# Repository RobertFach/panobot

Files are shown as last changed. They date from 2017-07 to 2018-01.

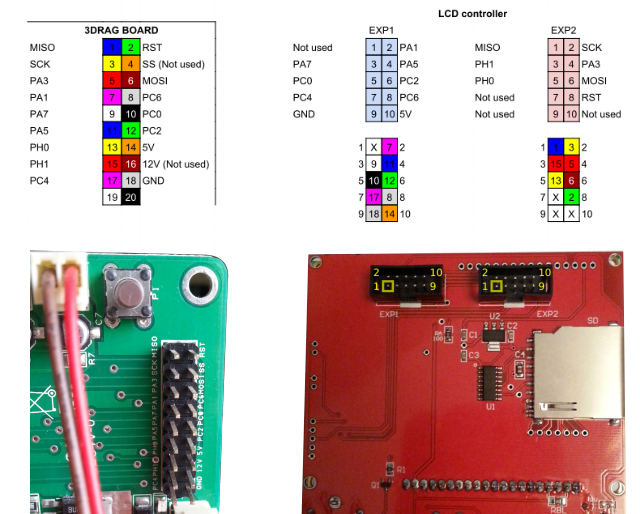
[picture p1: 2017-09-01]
hardware/pin_table-full-graphic-smart-controller.png

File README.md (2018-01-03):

PANOBOT: A Panorama robot, version 1

Panobot is a full automatic robot, which can be used to create Panoramas and Gigapixels with small and large cameras (like DSLRs). The camera is mounted on a turret to allow pan/tilt motion. After programming the capture parameters, the robot will start to rotate the camera, taking one (or multiple) pictures per position and making sure that the capture positions have enough overlap.

Panobot has the following menu features:
 * Scan
   * starts a scan
 * Sphere
   * starts a spherical scan (360x180)
 * Take picture
   * allows to manually take a picture, this is usefull for testing the camera trigger connection
 * Setup
   * Pan Left, Pan Right, Tilt Up, Tilt Down
     * defines the scan area of the panorama/gigapixel, the head will move while the range is defined, this is used for a normal scan
   * Image P-Delay
     * the longer, the more time the camera has to measure and (eventually focus, if not in manual camera mode), triggers focusing of camera
   * Image Delay
     * the delay it take for the camera to write the image to the card and/or the time it needs to stabilize the mechanical system due to rotating motion
   * Shutter Delay
     * how long the shutter will be pressed
   * Focal Length
     * the focal length which is currently by the camera
   * Horizontal& Vertical Overlap
     * defines the overlap between consecutive images, a value between 30% and 50% makes sense, usually depends on the capture situation
   * Crop factor
     * in combination with the focal length, can be used to calculate field of view, which is required for horizontal&vertical overlap

Required Hardware:
 * 3d printed parts
   * Please have a look at [Panobot at Thingiverse](https://www.thingiverse.com/thing:2503118) to find out the parts that need to be printed
 * mechanical parts
   * some screws, washers, nuts M3, M4
   * some bearings 608 (around 10)
   * some rods 8mm (for structure and as axis)
 * electronic parts
   * 2 stepper motors Nema17, like 42BYGHM810
   * Arduino Mega 2560
   * Reprap Full Graphic SmartLCD with clickencoder
   * the controller PCB in version 1.1.0, which consists of two stepper drivers A4988 and two optocopplers; you can build your own pcb (see pcb folder) or get one...

Required Software:
   * install atom editor
     * https://atom.io/ -> install deb
   * follow steps on http://platformio.org/get-started/ide?install=atom
     * install platformio-ide package inside atom
   * code completion
     * apt-get install clang

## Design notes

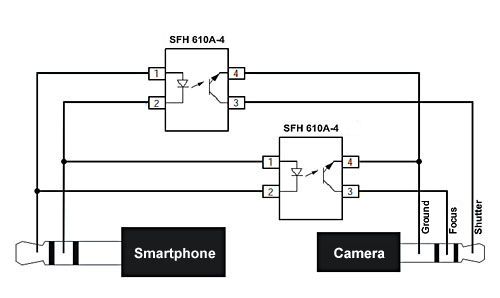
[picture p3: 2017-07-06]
hardware/OPTO-Canon-Trigger.jpeg

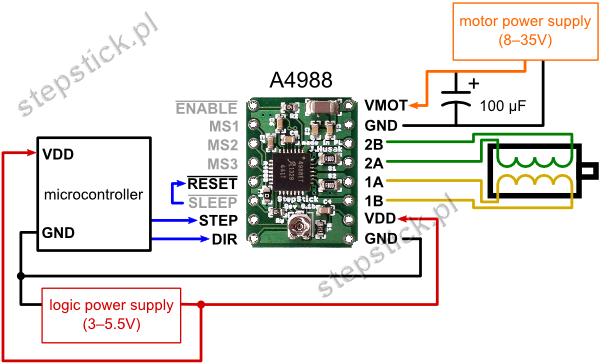
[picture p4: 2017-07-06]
hardware/stepstick-a4988.png

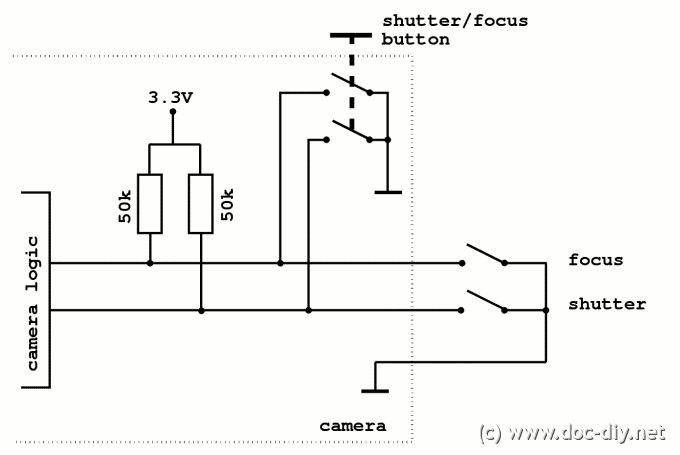
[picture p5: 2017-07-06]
hardware/canon-eos-remote-shutter.png

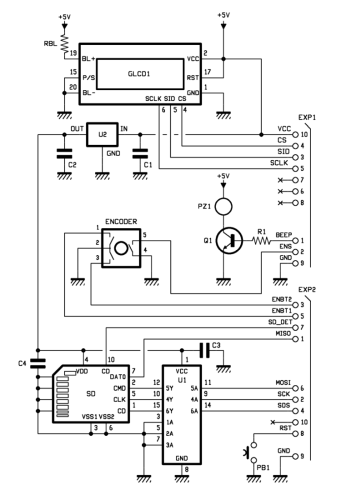
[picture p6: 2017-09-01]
hardware/1193_Schema-full-graphic-smart-controller.png

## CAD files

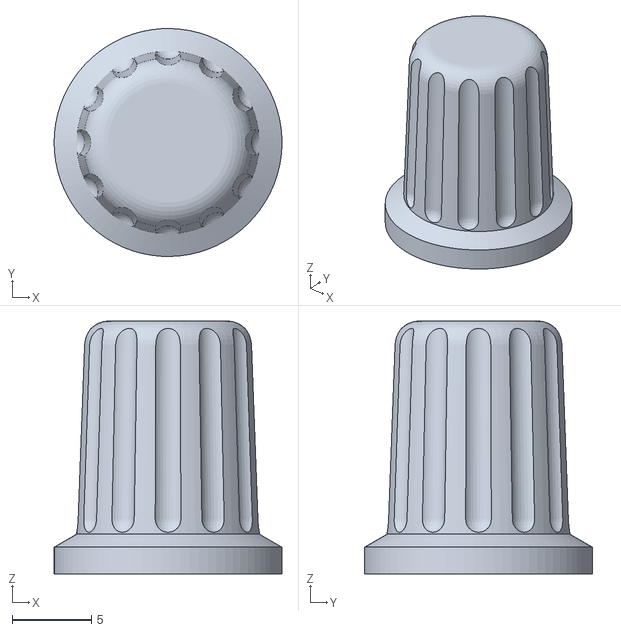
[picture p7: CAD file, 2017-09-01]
model/Case_for_the_Full_Graphic_Smart_LCD_Controller/files/controller_knob_2.stl
14.4 x 14.4 x 16.0

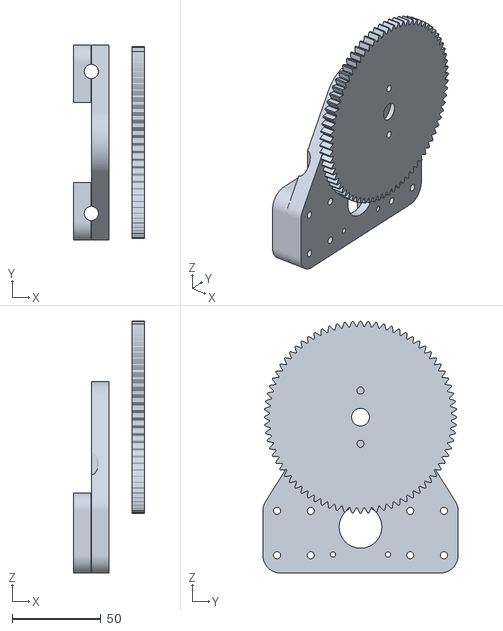
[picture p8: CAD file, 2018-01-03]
model/improved_tilt_axis.stl
40.1 x 110.0 x 141.9

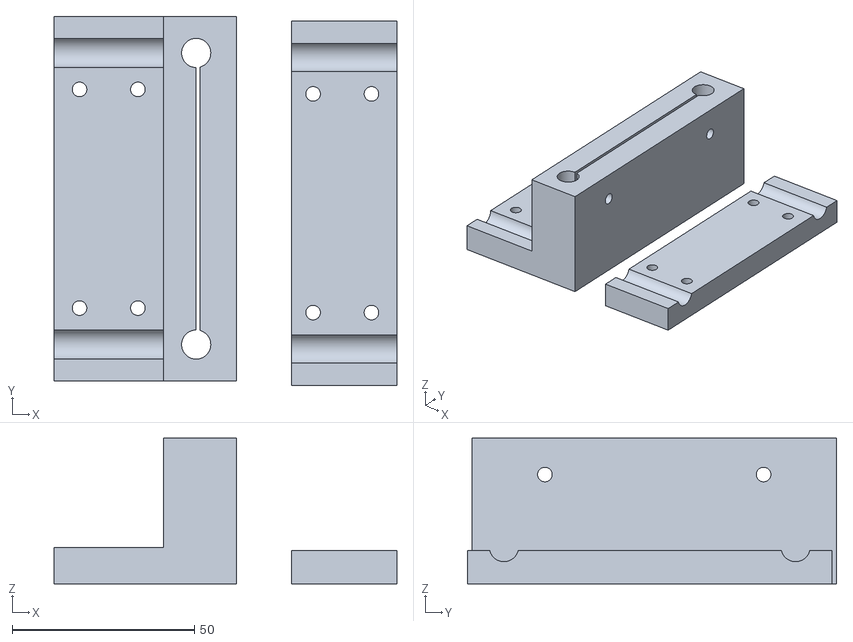
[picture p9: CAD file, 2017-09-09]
model/print/pantiltconnector_print.stl
94.1 x 101.2 x 40.0

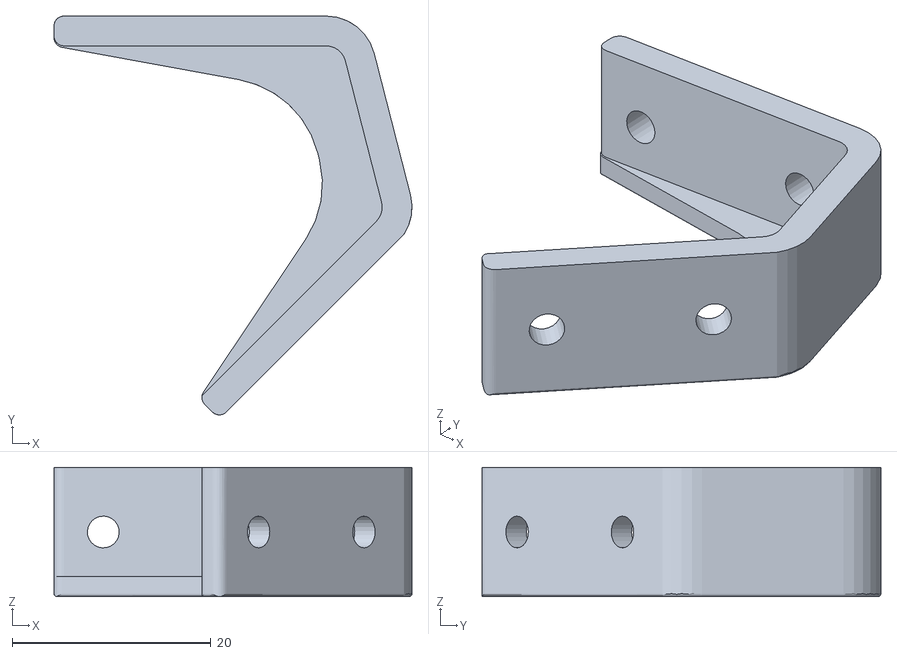
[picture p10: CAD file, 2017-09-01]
model/Case_for_the_Full_Graphic_Smart_LCD_Controller/files/mount_18_mm.stl
36.0 x 40.1 x 13.0

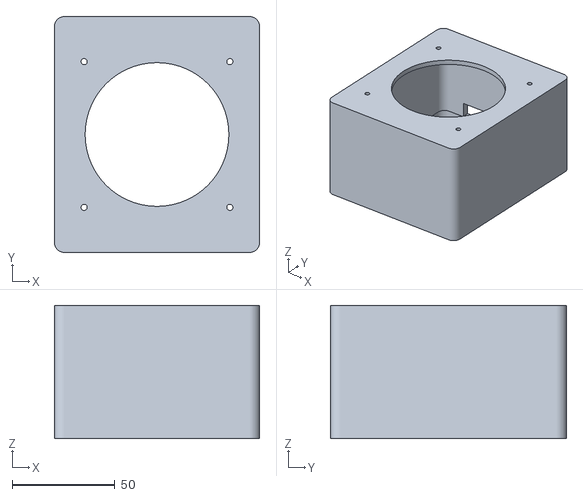
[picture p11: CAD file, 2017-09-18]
model/controller_case_cover.stl
100.0 x 115.0 x 65.0

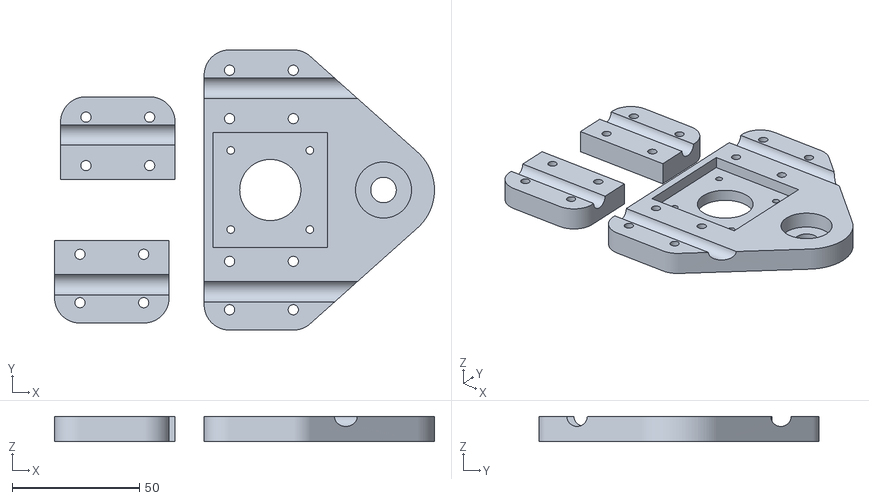
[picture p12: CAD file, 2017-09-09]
model/print/tiltsteppermount_print.stl
149.1 x 110.0 x 10.0

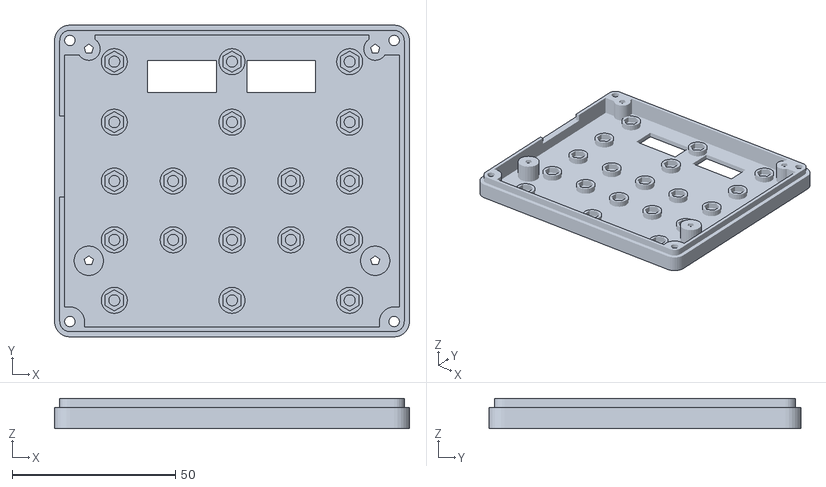
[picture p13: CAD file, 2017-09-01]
model/Case_for_the_Full_Graphic_Smart_LCD_Controller/files/Bottom_Case_FGD-_pockets.stl
108.6 x 95.4 x 9.30

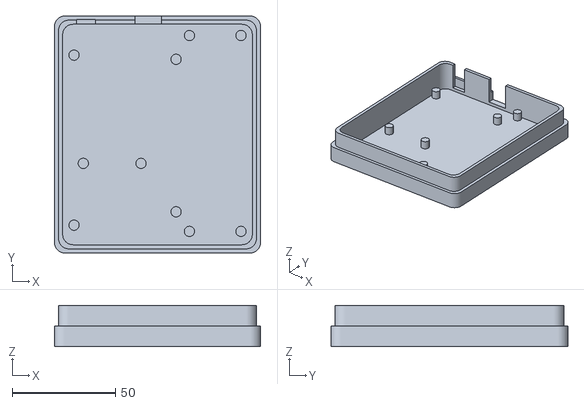
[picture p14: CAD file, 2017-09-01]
model/controller_case_bottom.stl
100.0 x 115.0 x 20.0

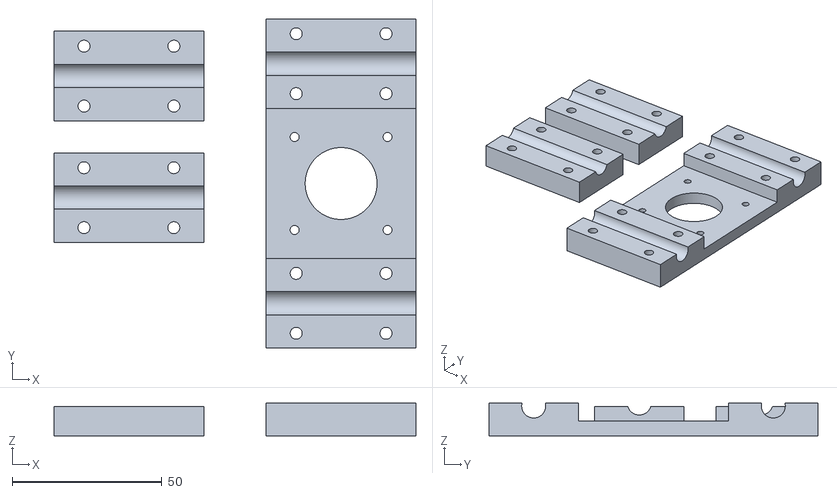
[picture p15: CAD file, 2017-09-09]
model/print/stepper_pan_mount_print.stl
120.9 x 110.0 x 11.0

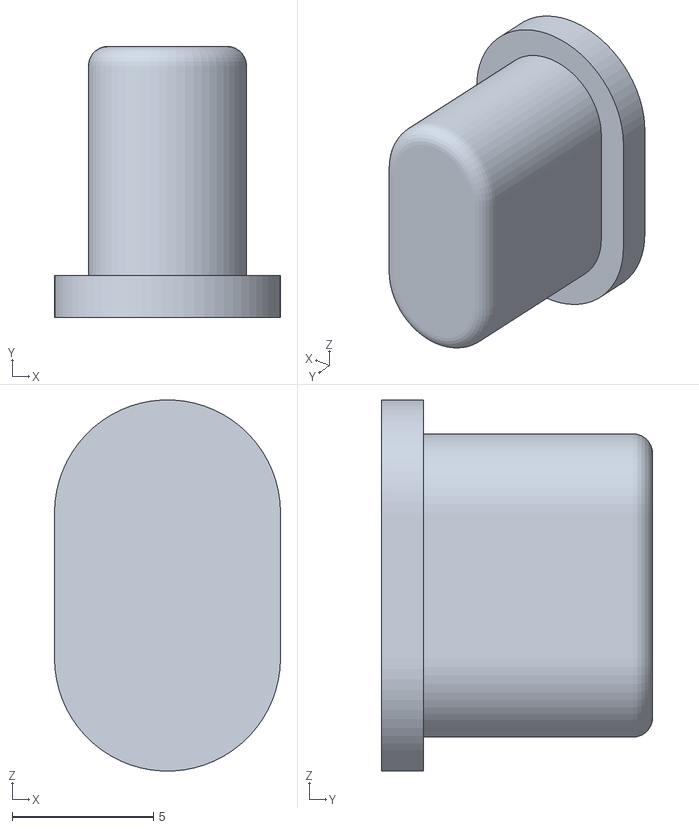
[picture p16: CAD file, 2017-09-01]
model/Case_for_the_Full_Graphic_Smart_LCD_Controller/files/Kill_Button_FGD.stl
8.00 x 9.60 x 13.1

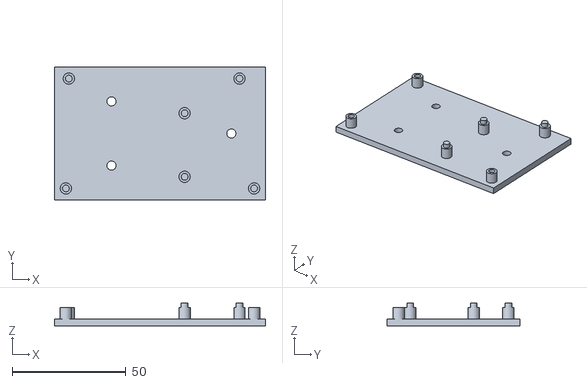
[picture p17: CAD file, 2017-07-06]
model/megamount.stl
92.6 x 58.2 x 10.00

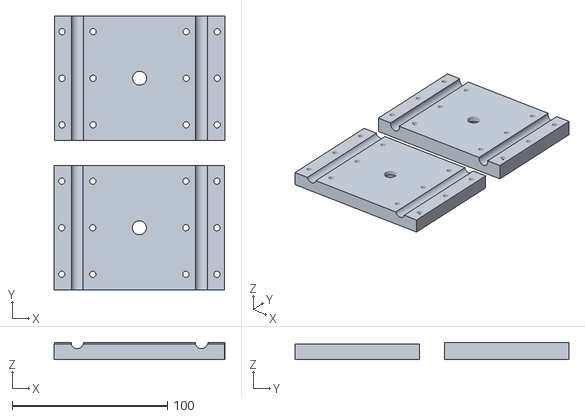
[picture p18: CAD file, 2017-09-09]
model/print/central_pan_print.stl
110.2 x 176.3 x 11.0

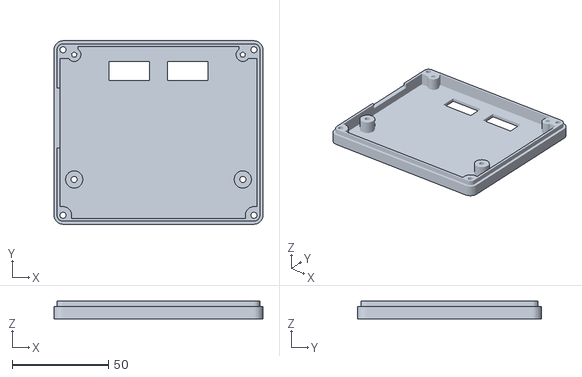
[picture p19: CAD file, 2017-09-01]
model/Case_for_the_Full_Graphic_Smart_LCD_Controller/files/Bottom_Case_FGD.stl
108.6 x 95.4 x 9.30

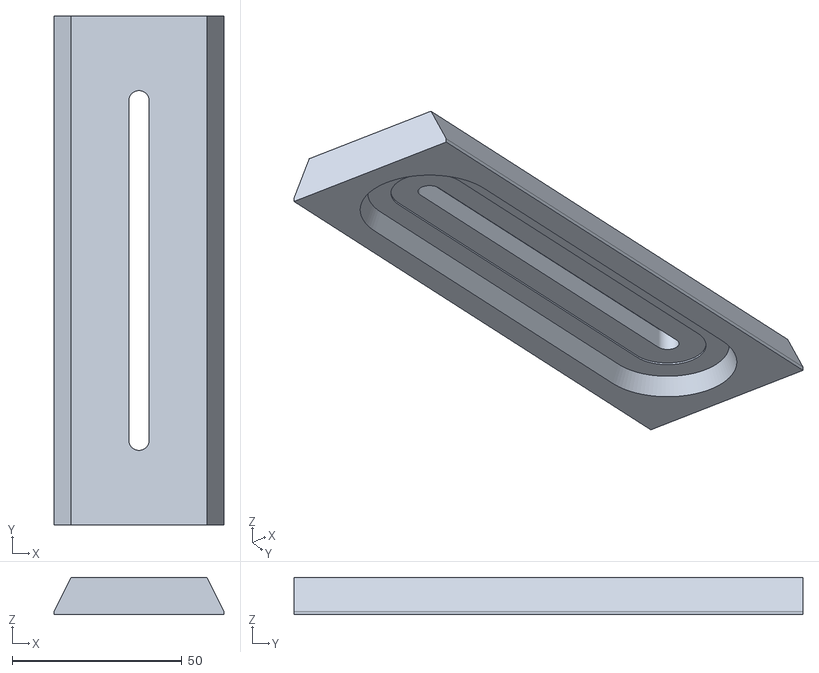
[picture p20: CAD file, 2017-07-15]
model/print/camquickmount_andoer.stl
50.0 x 150.0 x 11.0

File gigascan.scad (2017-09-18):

use <MCAD/involute_gears.scad>
use <MCAD/bearing.scad>
use <MCAD/nuts_and_bolts.scad>
use <MCAD/motors.scad>
include <MCAD/stepper.scad>
include <MCAD/boxes.scad>

$fn=100;

module mountgear() {
difference() {
union() {
    gear (
	number_of_teeth=81,
	circular_pitch=250, diametral_pitch=20,
	pressure_angle=28,
	clearance = 0.2,
	gear_thickness=7,
	rim_thickness=15,
	rim_width=5,
	hub_thickness=10,
	hub_diameter=15,
	bore_diameter=5,
	circles=0,
	backlash=0,
	twist=0,
	involute_facets=0,
	flat=false);
    //cylinder(r=15,h=20);
    cylinder(r1=45,r2=15,h=20);
}   
    translate([0,0,20-7+0.01])bearing(608,outline=true);
    translate([0,0,-0.01])bearing(608,outline=true);
    cylinder(r=4.1,h=50,center=true);
    
    rotate([0,0,45])translate([25,0,10+0.01])rotate([180,0,0])nutHole(4);
    rotate([0,0,45])translate([25,0,-0.01])cylinder(r=2,h=20);
    rotate([0,0,45])translate([25,0,10])cylinder(r=5,h=20);

    rotate([0,0,45])translate([-25,0,10+0.01])rotate([180,0,0])nutHole(4);
    rotate([0,0,45])translate([-25,0,-0.01])cylinder(r=2,h=20);
    rotate([0,0,45])translate([-25,0,10])cylinder(r=5,h=20);
}

}

module drivegear() {
    union() {
translate([56.25+9.02,0,0])gear (
	number_of_teeth=13,
	circular_pitch=250, diametral_pitch=20,
	pressure_angle=28,
	clearance = 0.2,
	gear_thickness=10,
	rim_thickness=15,
	rim_width=5,
	hub_thickness=10,
	hub_diameter=15,
	bore_diameter=5,
	circles=0,
	backlash=0,
	twist=0,
	involute_facets=0,
	flat=false);
        translate([56.25+9.02+1.9,-4,0])cube([3,8,15]);
    }
}

module pan() {
    difference() {
        union() {
            translate([-55,-40,21])cube([110,80,21]);
            translate([0,0,22])cylinder(r=15,h=20);
        }
        rotate([90,0,0])translate([40,31,-150])cylinder(r=4,h=300);
        rotate([90,0,0])translate([-40,31,-150])cylinder(r=4,h=300);
    //translate([0,56.25+9.02,28])rotate([180,0,0])stepper_motor_mount(17);
    
    cylinder(r=4.5,h=100);
    translate([0,0,20.9])bearing(608,outline=true);    
    translate([0,0,35.1])bearing(608,outline=true);
//    translate([20,23,31])minkowski(){
//        cylinder(r=8,h=10);
//        sphere(r=5);
//    }
//    translate([-20,23,31])minkowski(){
//        cylinder(r=8,h=10);
//        sphere(r=5);
//    }
//    translate([20,-23,31])minkowski(){
//        cylinder(r=8,h=10);
//        sphere(r=5);
//    }
//    translate([-20,-23,31])minkowski(){
//        cylinder(r=8,h=10);
//        sphere(r=5);
//    }
    translate([-150,-150,32])cube([300,300,0.1]);
    translate([30,30,0])cylinder(r=2,h=50);
    translate([50,30,0])cylinder(r=2,h=50);
    translate([30,0,0])cylinder(r=2,h=50);
    translate([50,0,0])cylinder(r=2,h=50);
    translate([30,-30,0])cylinder(r=2,h=50);
    translate([50,-30,0])cylinder(r=2,h=50);

    translate([-30,30,0])cylinder(r=2,h=50);
    translate([-50,30,0])cylinder(r=2,h=50);
    translate([-30,0,0])cylinder(r=2,h=50);
    translate([-50,0,0])cylinder(r=2,h=50);
    translate([-30,-30,0])cylinder(r=2,h=50);
    translate([-50,-30,0])cylinder(r=2,h=50);

  }    
}

module stepper() {
    motor(model=Nema17, size=NemaLong, dualAxis=false, pos=[56.25+9.02,0,25], orientation = [0,0,0]);
}

module steppermount() {
    difference() {
        translate([56.25+9.02-25,-55,21])cube([50,110,21]);
        //stepper();
        rotate([90,0,90])translate([40,31,-150])cylinder(r=4,h=300);
        rotate([90,0,90])translate([-40,31,-150])cylinder(r=4,h=300);        
    translate([56.25+9.02-26,-25,26])cube([55,50,30]);
    translate([56.25+9.02-25,-55,32])cube([300,300,0.1]);

    translate([56.25+9.02+31.04/2,31.04/2,0])cylinder(r=1.5,h=50);    
    translate([56.25+9.02-31.04/2,31.04/2,0])cylinder(r=1.5,h=50);    
    translate([56.25+9.02+31.04/2,-31.04/2,0])cylinder(r=1.5,h=50);    
    translate([56.25+9.02-31.04/2,-31.04/2,0])cylinder(r=1.5,h=50);
    
    translate([56.25+9.02,0,0])cylinder(r=12,h=50);    
        
    translate([56.25+9.02-15,30,0])cylinder(r=2,h=50);
    translate([56.25+9.02-15,50,0])cylinder(r=2,h=50);
    translate([56.25+9.02+15,30,0])cylinder(r=2,h=50);
    translate([56.25+9.02+15,50,0])cylinder(r=2,h=50);
        
    translate([56.25+9.02-15,-30,0])cylinder(r=2,h=50);
    translate([56.25+9.02-15,-50,0])cylinder(r=2,h=50);
    translate([56.25+9.02+15,-30,0])cylinder(r=2,h=50);
    translate([56.25+9.02+15,-50,0])cylinder(r=2,h=50);
    }
}

module panrods() {
    rotate([90,0,90])translate([40,31,-150])cylinder(r=4,h=300);
    rotate([90,0,90])translate([-40,31,-150])cylinder(r=4,h=300);    
}

module tiltsiderods() {
    rotate([0,0,90])translate([40,130,35])cylinder(r=4,h=100);
    rotate([0,0,90])translate([-40,130,35])cylinder(r=4,h=100);    
}

module tiltbaserods() {
    rotate([90,0,90])translate([30,100,-100.1])cylinder(r=4,h=200.2);
    rotate([90,0,90])translate([-30,100,-100.1])cylinder(r=4,h=200.2);    
}

module tiltside() {
    difference() {
        hull() {
            rotate([90,0,90])translate([0,145,100-10])cylinder(r=20,h=10);
            rotate([90,0,90])translate([-30,100,100-10])cylinder(r=10,h=10);
            rotate([90,0,90])translate([30,100,100-10])cylinder(r=10,h=10);
        }
        rotate([90,0,90])translate([-30,100,100-10-5])cube([60,1,1000]);            
       hull() {
           rotate([90,0,90])translate([-25,110,100-10.1])cylinder(r=3,h=11);
           rotate([90,0,90])translate([25,110,100-10.1])cylinder(r=3,h=11);
           rotate([90,0,90])translate([-10,120,100-10.1])cylinder(r=5,h=11);
           rotate([90,0,90])translate([10,120,100-10.1])cylinder(r=5,h=11);
       }
        
        rotate([90,0,90])translate([0,145,100-10-0.1])bearing(608,outline=true);
        rotate([90,0,90])translate([0,145,100-10-0.1])cylinder(r=5,h=100);
       
       rotate([90,0,90])translate([-20,110,100-5])rotate([90,0,0])cylinder(r=2,h=30);
       rotate([90,0,90])translate([20,110,100-5])rotate([90,0,0])cylinder(r=2,h=30);
    
    rotate([90,0,90])translate([30,100,-100.1])cylinder(r=4,h=200.2);
    rotate([90,0,90])translate([-30,100,-100.1])cylinder(r=4,h=200.2);    
    }

}

module tiltsidedrive() {
    difference() {
        rotate([0,0,180])tiltside();
        rotate([0,0,180])rotate([90,0,90])translate([0,130,100-10-0.1])cylinder(r=2,h=20);
        rotate([0,0,180])rotate([90,0,90])translate([0,160,100-10-0.1])cylinder(r=2,h=40);
    }
}

module tiltsidedrivegear() {
    difference() {
        union() {
        rotate([0,0,180])rotate([90,0,90])translate([0,145,100])
    gear (
	number_of_teeth=51,
	circular_pitch=250, diametral_pitch=20,
	pressure_angle=28,
	clearance = 0.2,
	gear_thickness=7,
	rim_thickness=14,
	rim_width=5,
	hub_thickness=14,
	hub_diameter=39,
	bore_diameter=10,
	circles=0,
	backlash=0,
	twist=0,
	involute_facets=0,
	flat=false);
//        rotate([0,0,180])rotate([90,0,90])translate([0,145,100+4+0.1])cylinder(r1=25,r2=20,h=11);
        }
        rotate([0,0,180])rotate([90,0,90])translate([0,145,107+0.1])bearing(608,outline=true);
//        rotate([0,0,180])rotate([90,0,90])translate([0,145,100-10+0.1])cylinder(r=5,h=50);
        rotate([0,0,180])rotate([90,0,90])translate([0,130,100-10-0.1])cylinder(r=2,h=40);
        rotate([0,0,180])rotate([90,0,90])translate([0,160,100-10-0.1])cylinder(r=2,h=40);
    }   
}

module tiltsidesteppergear() {
    union() {
        rotate([0,0,180])rotate([90,0,90])translate([0,145-35.4167-9.02778,100])
    gear(
	number_of_teeth=13,
	circular_pitch=250, diametral_pitch=20,
	pressure_angle=28,
	clearance = 0.2,
	gear_thickness=15,
	rim_thickness=15,
	rim_width=5,
	hub_thickness=10,
	hub_diameter=15,
	bore_diameter=5,
	circles=0,
	backlash=0,
	twist=0,
	involute_facets=0,
	flat=false);
        rotate([0,0,180])rotate([90,0,90])translate([1.9,145-35.4167-9.02778-4,100])cube([3,8,15]);
    }   
}

module tiltsidestepper() {
    rotate([0,0,180])rotate([90,0,90])translate([0,145-35.4167-9.02778,100])motor(model=Nema17, size=NemaLong, dualAxis=false, pos=[0,0,25], orientation = [0,0,0]);
}
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

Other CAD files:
model/tiltsteppermount.stl
model/Case_for_the_Full_Graphic_Smart_LCD_Controller/files/Spacer_FGD.stl
model/print/quickmountclamp.stl
model/stepper_pan_mount.stl
model/Case_for_the_Full_Graphic_Smart_LCD_Controller/files/Case_Clamp.stl
model/Case_for_the_Full_Graphic_Smart_LCD_Controller/files/Top_Case_FGD.stl
model/central_pan.stl
model/gigascan.stl
model/pantiltconnector.stl
model/print/camquickmount.stl
model/print/central_gear.stl
model/print/drivegear.stl
model/print/tiltside.stl
model/print/tiltsidedrive.stl
model/print/tiltsidedrivegear.stl
model/print/tiltsidesteppergear.stl

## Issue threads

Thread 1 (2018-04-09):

PCB

darkmaterial, 2018-04-09:
Hello Robert,
would it be possible to Upload your EAGLE PCB Files?  I would like to remove the Ardunioboard and create a new one with Atmeg256 onboard.

RobertFach, 2018-04-20:
Hi,
at the moment I have no 100% opinion about it.
Although everything is open for rebuild, I'm a little bit scared to share the eagle files because of the following reasons:
- It would make it pretty easy for everyone (especially commercial chinese pcb producers) to clone this work and sell the boards. Including all advantages and disadvantages...
- I want to keep control over the hardware because I have several plans with extensions. (The next revision of the board will most probably move to a 32bit core to get some additional processing power.)

Do you have a special use case why you need both combined?

Cheers,

darkmaterial, 2018-11-01:
Closed, see fork

Closed 2018-11-01.

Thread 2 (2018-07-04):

Scan rotation error

DrJuJu, 2018-07-04:
When configuring the pan left\right settings, instead of the rotation going incrementally in 10 degree steps, it appears to be adding the next step size to the existing value, so that when getting closer to 180 degrees, the mount fully rotates.

This behaviour is also seen when the scan is selected. The mount rotates a number of full revolutions, before starting to take pictures.

DrJuJu, 2018-07-04:
I'm going to close this for now, as there seems to be a problem between keyboard and chair, i.e. Me not thinking things through properly. It also doesn't help that some of my drivers\wiring are intermittent....
But I'm just about there with the 1.2.0 setup....

Closed 2018-07-04.

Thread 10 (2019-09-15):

PCB

jaygrovr, 2019-09-15:
Can you post gerber files and screen files so i can get a board or two made?  I would probably go to oshpark and get a few made if I had the files.

Thanks

zombodotcom, 2019-09-15:
He has omg files and the schematic up shouldn't be too difficult to find some conversion programs or to make it yourself in fritzing

glowfishDE, 2020-04-19:
+1 Please post the gerber files or a link where you can buy PCBs. A picture and/or the schematic is not
sufficient

darkmaterial, 2021-05-20:
Check Out, you get a compatible PCB there:
https://github.com/darkmaterial/panobot

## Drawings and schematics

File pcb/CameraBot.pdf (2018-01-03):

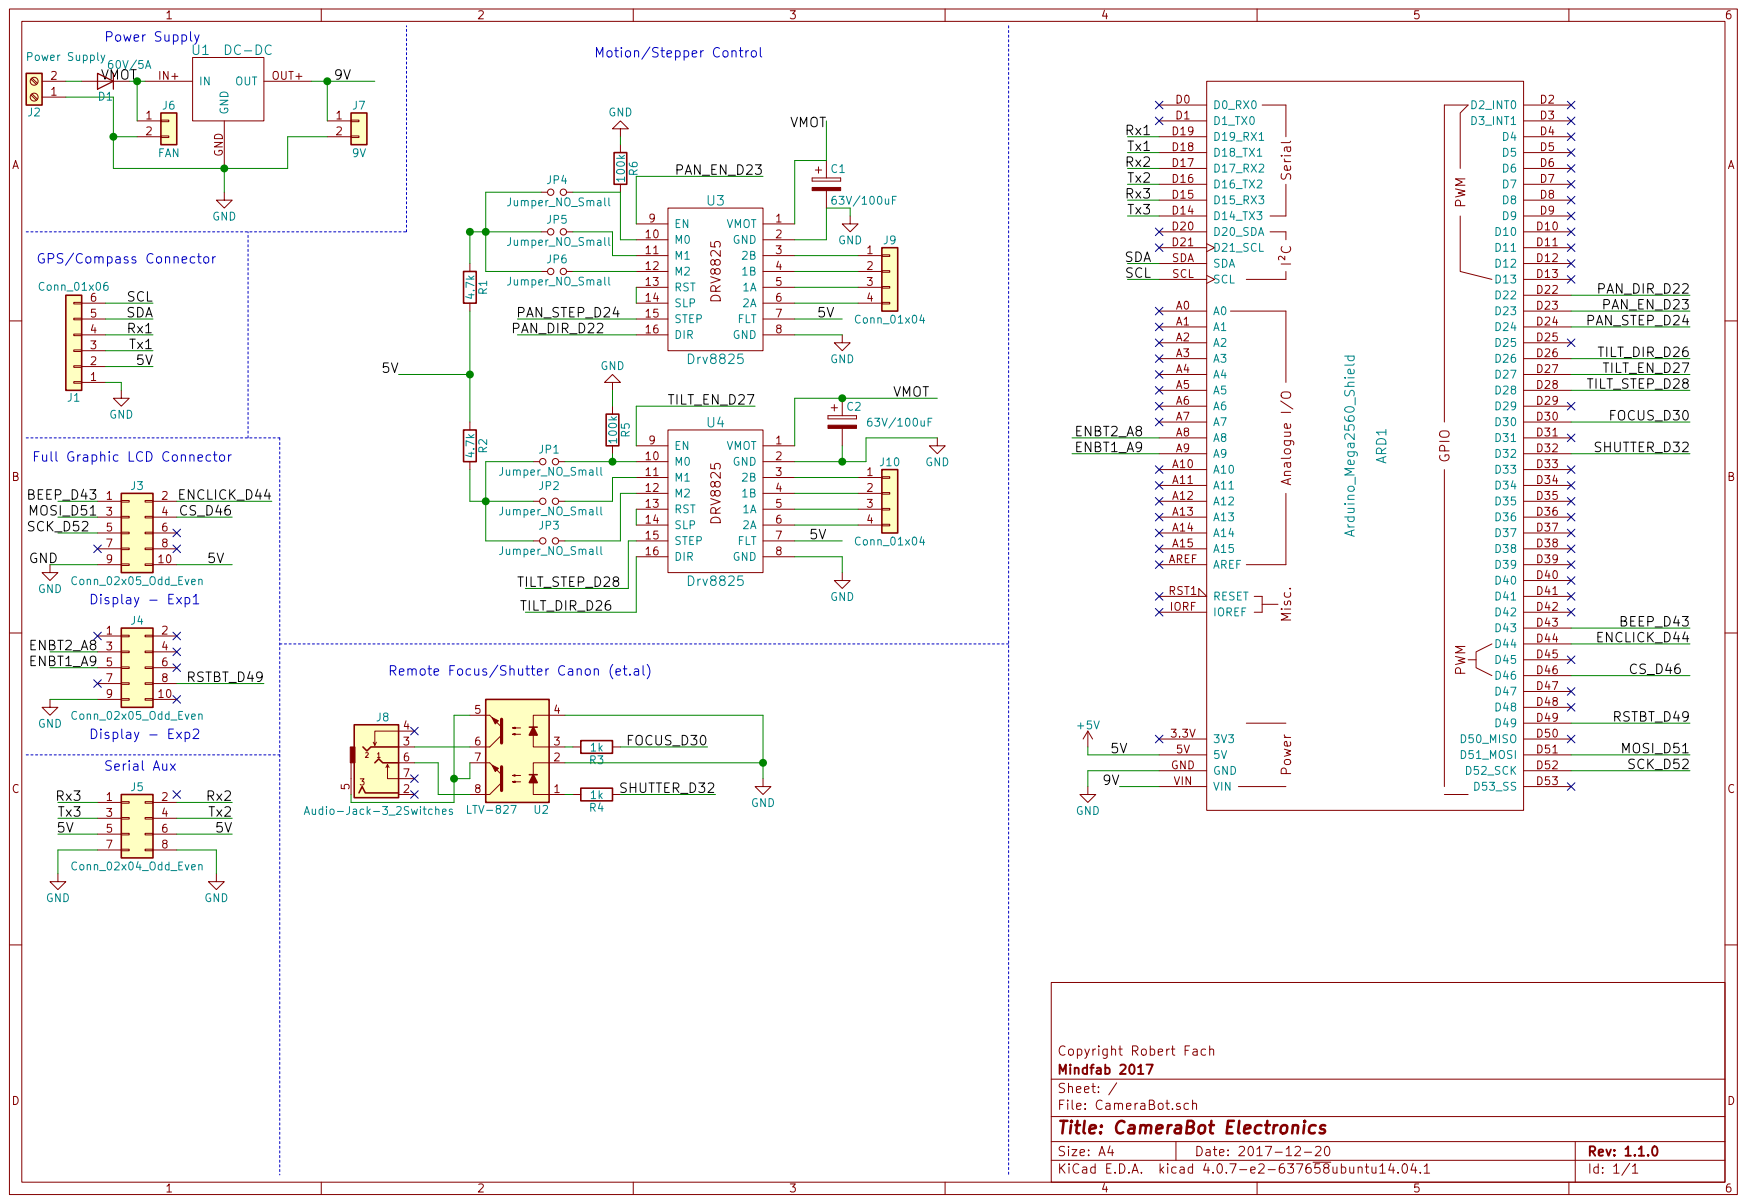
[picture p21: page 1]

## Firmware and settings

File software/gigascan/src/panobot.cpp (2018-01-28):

/* Copyright (C) 2017 Robert Fach All rights reserved.

This software may be distributed and modified under the terms of the GNU
General Public License version 2 (GPL2) as published by the Free Software
Foundation and appearing in the file GPL2.TXT included in the packaging of
this file. Please note that GPL2 Section 2[b] requires that all works based
on this software must also be made publicly available under the terms of
the GPL2 ("Copyleft").

Contact information
-------------------

Robert Fach
e-mail   :  robert.fach@gmx.net
*/

#include <Arduino.h>
#include <Streaming.h>

#ifdef ESP8266
  #define typeof(x) __typeof__(x)
  #include <SPI.h>
  #include <Wire.h>
#endif

#include <config.h>
#include <eeprom-config.h>

#include <AccelStepper.h>
#include <math.h>

#include <menu.h>
#include <menuIO/chainStream.h>
#include <menuIO/serialOut.h>
#include <menuIO/u8g2Out.h>
#include <menuIO/encoderIn.h>
#include <menuIO/keyIn.h>

using namespace Menu;

//panobot logic & motor control
AccelStepper panStepper(AccelStepper::DRIVER, PAN_STEP_PIN, PAN_DIR_PIN);
AccelStepper tiltStepper(AccelStepper::DRIVER, TILT_STEP_PIN, TILT_DIR_PIN);

boolean g_runScan = false;
boolean g_isMaxPanLeftSetup = false;
boolean g_isMaxPanRightSetup = false;
boolean g_isPanStepSetup = false;
boolean g_isMaxTiltUpSetup = false;
boolean g_isMaxTiltDownSetup = false;
boolean g_isTiltStepSetup = false;
boolean g_updateStatus = true;

double g_panStepDeg = 0;
double g_tiltStepDeg = 0;
int g_scanPositionHorizontal = 0;
int g_scanPositionVertical = 0;
int g_picturesHorizontal = 0;
int g_picturesVertical = 0;
int g_picturesCount = 0;
int g_picturesTotal = 0;
double panPos = 0;
double tiltPos = 0;

double g_sensorFF_horizontal = 36.0;
double g_sensorFF_vertical = 24.0;
double g_hfov = 0;
double g_vfov = 0;


//callback function used by the menu to do the math when updating some values
void updateScanner() {
  g_hfov = degrees( 2 * atan2(g_sensorFF_horizontal, user_config.crop_factor * 2 * user_config.focal_length));
  g_vfov = degrees( 2 * atan2(g_sensorFF_vertical, user_config.crop_factor * 2 * user_config.focal_length));
  g_panStepDeg = g_hfov * (100 - user_config.horizontal_overlap) / 100;
  g_tiltStepDeg = g_vfov * (100 - user_config.vertical_overlap) / 100;
  g_picturesHorizontal = ceil((abs(user_config.scan_max_pan_left) + abs(user_config.scan_max_pan_right)) / g_panStepDeg);
  g_picturesVertical = ceil((abs(user_config.scan_max_tilt_up) + abs(user_config.scan_max_tilt_down)) / g_tiltStepDeg);
  g_picturesTotal = g_picturesHorizontal * g_picturesVertical;
  Serial.print("HSCAN: "); Serial.println(abs(user_config.scan_max_pan_left) + abs(user_config.scan_max_pan_right), DEC);
  Serial.print("VSCAN: "); Serial.println(abs(user_config.scan_max_tilt_up) + abs(user_config.scan_max_tilt_down), DEC);
  Serial.print("g_hfov: "); Serial.println(g_hfov,DEC);
  Serial.print("g_vfov: "); Serial.println(g_vfov,DEC);
  Serial.print("g_panStepDeg: "); Serial.println(g_panStepDeg,DEC);
  Serial.print("g_tiltStepDeg: "); Serial.println(g_tiltStepDeg,DEC);
  Serial.print("g_picturesHorizontal: "); Serial.println(g_picturesHorizontal, DEC);
  Serial.print("g_picturesVertical: "); Serial.println(g_picturesVertical, DEC);
  Serial.print("g_picturesTotal: "); Serial.println(g_picturesTotal, DEC);
  //g_updateStatus = true;
}

void updateMaxPanLeftPosition(eventMask e) {
  if (e & exitEvent) {
    panStepper.moveTo(0);
  } else {
    panStepper.moveTo(user_config.scan_max_pan_left * user_config.pan_steps_per_degree);
  }
  updateScanner();
}
void updateMaxPanRightPosition(eventMask e) {
  if (e & exitEvent) {
    panStepper.moveTo(0);
  } else {
    panStepper.moveTo(user_config.scan_max_pan_right * user_config.pan_steps_per_degree);
  }
  updateScanner();
}

void updateMaxTiltUpPosition(eventMask e) {
  if (e & exitEvent) {
    tiltStepper.moveTo(0);
  } else {
    tiltStepper.moveTo(user_config.scan_max_tilt_up * user_config.tilt_steps_per_degree);
  }
  updateScanner();
}

void updateMaxTiltDownPosition(eventMask e) {
  if (e & exitEvent) {
    tiltStepper.moveTo(0);
  } else {
    tiltStepper.moveTo(user_config.scan_max_tilt_down * user_config.tilt_steps_per_degree);
  }
  updateScanner();
}

void printScannerStats() {
  Serial.print("H[");
  Serial.print(g_scanPositionHorizontal+1, DEC);
  Serial.print("/");
  Serial.print(g_picturesHorizontal, DEC);
  Serial.println("]");
  Serial.print("V[");
  Serial.print(g_scanPositionVertical+1, DEC);
  Serial.print("/");
  Serial.print(g_picturesVertical, DEC);
  Serial.println("]");
  Serial.print("T[");
  Serial.print(g_picturesCount, DEC);
  Serial.print("/");
  Serial.print(g_picturesTotal, DEC);
  Serial.println("]");
}

typedef enum {
  IDLE,
  POSITIONING,
  STABILIZE_WAIT,
  FOCUS_WAIT,
  TRIGGER_WAIT,
  FINISH
} eSystemState;

typedef enum {
  ZICK_ZACK_LEFT_RIGHT_DOWN_UP,
  SPHERICAL
} eSystemModePattern;

eSystemState state = IDLE;
eSystemModePattern modePattern = ZICK_ZACK_LEFT_RIGHT_DOWN_UP;
long delayTime = 0;
long startTime = 0;

void runScanCallback()
{
  g_runScan = true;
  g_scanPositionHorizontal = 0;
  g_scanPositionVertical = 0;
  g_updateStatus = true;
  modePattern = ZICK_ZACK_LEFT_RIGHT_DOWN_UP;
}

void runSphereCallback()
{
  g_runScan = true;
  modePattern = SPHERICAL;
  g_picturesTotal = 0;
}

eSystemState updatePosition(eSystemState state, eSystemModePattern mode) {
   if (state == IDLE) {
      if (mode == ZICK_ZACK_LEFT_RIGHT_DOWN_UP) {
        g_updateStatus = true;
        panPos = user_config.scan_max_pan_left;
        tiltPos = user_config.scan_max_tilt_down;
      } else if (mode == SPHERICAL) {
        panPos = 0;
        tiltPos = -60;
      }
   } else {
      if (mode == ZICK_ZACK_LEFT_RIGHT_DOWN_UP) {
        g_updateStatus = true;
        if (g_scanPositionHorizontal >= g_picturesHorizontal-1) {
          if (g_scanPositionVertical >= g_picturesVertical-1) {
            g_runScan = false;
            panPos = 0;
            tiltPos = 0;
            tiltStepper.moveTo(tiltPos * user_config.tilt_steps_per_degree);
            panStepper.moveTo(panPos * user_config.pan_steps_per_degree);
            return FINISH;
          } else {
            tiltPos += g_tiltStepDeg;
          }
          panPos = user_config.scan_max_pan_left;
          g_scanPositionHorizontal = 0;
          g_scanPositionVertical++;
        } else {
          panPos += g_panStepDeg;
          g_scanPositionHorizontal++;
        }
      } else if (mode == SPHERICAL) {

        if (panPos > 360 || tiltPos == 90) {
          if (tiltPos == 90) {
            g_runScan = false;
            panPos = 0;
            tiltPos = 0;
            tiltStepper.moveTo(tiltPos * user_config.tilt_steps_per_degree);
            panStepper.moveTo(panPos * user_config.pan_steps_per_degree);
            return FINISH;
          } else {
            tiltPos += g_tiltStepDeg;
            if (tiltPos > 90) {
              tiltPos = 90;
            }
          }
          panPos = 0;
          panStepper.setCurrentPosition(0);
        } else {
          if (tiltPos != 90) {
            panPos += abs(floor(g_panStepDeg * 1 / cos( radians(tiltPos))));
          }
        }
      }
   }
   tiltStepper.moveTo(tiltPos * user_config.tilt_steps_per_degree);
   panStepper.moveTo(panPos * user_config.pan_steps_per_degree);
   return POSITIONING;
}

void stateMachine() {
  if (state == IDLE && g_runScan) {
    state = updatePosition(state, modePattern);
  }
  if (state == POSITIONING) {
    if (tiltStepper.distanceToGo() == 0 && panStepper.distanceToGo() == 0) {
      delayTime = user_config.stabilize_and_write_delay;
      startTime = millis();
      state = STABILIZE_WAIT;
    }
  }
  if (state == STABILIZE_WAIT) {
    if (millis() - startTime > delayTime) {
      digitalWrite(FOCUS_PIN, HIGH);
      delayTime = user_config.focus_delay;
      startTime = millis();
      state = FOCUS_WAIT;
    }
  }
  if (state == FOCUS_WAIT) {
    if (millis() - startTime > delayTime) {
      digitalWrite(SHUTTER_PIN, HIGH);
      delayTime = user_config.trigger_delay;
      startTime = millis();
      state = TRIGGER_WAIT;
    }
  }
  if (state == TRIGGER_WAIT) {
    if (millis() - startTime > delayTime) {
      g_picturesCount++;
      g_updateStatus = true;
      printScannerStats();
      digitalWrite(FOCUS_PIN, LOW);
      digitalWrite(SHUTTER_PIN, LOW);
      state = updatePosition(state,modePattern);
    }
  }
  if (state == FINISH) {
    if (tiltStepper.distanceToGo() == 0 && panStepper.distanceToGo() == 0) {
      state = IDLE;
    }
  }
}

void initializeSteppers() {
  panStepper.setMaxSpeed(user_config.maximum_pan_speed);
  panStepper.setAcceleration(user_config.pan_acceleration);
  panStepper.setPinsInverted(true,false,false);
  tiltStepper.setMaxSpeed(user_config.maximum_tilt_speed);
  tiltStepper.setAcceleration(user_config.tilt_acceleration);
  tiltStepper.setPinsInverted(false,false,false);
}

//initializes everything which is bot related
void setupPanoBot() {
  pinMode(FOCUS_PIN, OUTPUT);
  pinMode(SHUTTER_PIN, OUTPUT);
  digitalWrite(FOCUS_PIN, LOW);
  digitalWrite(SHUTTER_PIN, LOW);
  initializeSteppers();
  updateScanner();
  g_updateStatus = true;
}

void resetConfiguration() {
  resetToDefaultConfig();
  updateScanner();
}

//Panobot MENU system, it uses ArduinoMenu library in combination with U8g2

// define menu colors --------------------------------------------------------
//each color is in the format:
//  {{disabled normal,disabled selected},{enabled normal,enabled selected, enabled editing}}
// this is a monochromatic color table
const colorDef<uint8_t> colors[] MEMMODE={
  {{0,0},{0,1,1}},//bgColor
  {{1,1},{1,0,0}},//fgColor
  {{1,0},{1,0,0}},//valColor
  {{1,1},{1,0,0}},//unitColor
  {{0,1},{0,0,1}},//cursorColor
  {{0,0},{1,1,1}},//titleColor
};

#define fontName u8g2_font_5x7_tf
#define fontX 5
#define fontY 8
#define offsetX 5
#define offsetY 32
#define MAX_DEPTH 2

//initialize SmartLCD display, hardware SPI
U8G2_ST7920_128X64_F_HW_SPI u8g2(U8G2_R0, DISPLAY_CS_PIN, U8X8_PIN_NONE);

// Panobot Setup Menu
MENU(subMenuSetup,"Setup",doNothing,noEvent,noStyle
  ,FIELD(user_config.scan_max_pan_left,      "Pan Left     ","DEG",-200,0,10,1,updateMaxPanLeftPosition,enterEvent | exitEvent | updateEvent,wrapStyle)
  ,FIELD(user_config.scan_max_pan_right,     "Pan Right    ","DEG",0,200,10,1,updateMaxPanRightPosition,enterEvent | exitEvent | updateEvent,wrapStyle)
  ,FIELD(user_config.scan_max_tilt_up,       "Tilt UP      ","DEG",0,100,10,1,updateMaxTiltUpPosition,enterEvent | exitEvent | updateEvent,wrapStyle)
  ,FIELD(user_config.scan_max_tilt_down,     "Tilt Down    ","DEG",-90,0,10,1,updateMaxTiltDownPosition,enterEvent | exitEvent | updateEvent,wrapStyle)
  ,FIELD(user_config.stabilize_and_write_delay,"StWr Delay","ms",0,5000,1000,100,doNothing,noEvent,wrapStyle)
  ,FIELD(user_config.focus_delay,   "Focus Delay  ","ms",0,15000,1000,100,doNothing,noEvent,wrapStyle)
  ,FIELD(user_config.trigger_delay,       "Trigger Delay","ms",0,15000,1000,100,doNothing,noEvent,wrapStyle)
  ,FIELD(user_config.focal_length, "Focal Length ","mm",1,1000,10,1,updateScanner,enterEvent | exitEvent | updateEvent,wrapStyle)
  ,FIELD(user_config.horizontal_overlap, "Hor. Overlap ","%",0,100,10,1,updateScanner,enterEvent | exitEvent | updateEvent,wrapStyle)
  ,FIELD(user_config.vertical_overlap, "Ver. Overlap ","%",0,100,10,1,updateScanner,enterEvent | exitEvent| updateEvent,wrapStyle)
  ,FIELD(user_config.crop_factor, "Crop Factor  ","",0,10,0.1,0.01,updateScanner,enterEvent | exitEvent| updateEvent,wrapStyle)
  ,OP("Save", saveConfig, enterEvent)
  ,OP("Reset", resetConfiguration, enterEvent)
  ,EXIT("<Back")
);

MENU(subMenuHardware,"Hardware",doNothing,noEvent,noStyle
  ,FIELD(user_config.pan_steps_per_degree,  "PAN  ", "#/deg",0,1000,10,1, doNothing, noEvent, wrapStyle)
  ,FIELD(user_config.tilt_steps_per_degree, "TILT ", "#/deg",0,1000,10,1, doNothing, noEvent, wrapStyle)
  ,FIELD(user_config.maximum_pan_speed,     "Pan  Speed", "", 0, 5000, 100, 10, initializeSteppers, enterEvent | exitEvent| updateEvent, wrapStyle)
  ,FIELD(user_config.pan_acceleration,     "Pan  Accel", "", 0, 5000, 100, 10, initializeSteppers, enterEvent | exitEvent| updateEvent, wrapStyle)
  ,FIELD(user_config.maximum_tilt_speed,    "Tilt Speed", "", 0, 5000, 100, 10, initializeSteppers, enterEvent | exitEvent| updateEvent, wrapStyle)
  ,FIELD(user_config.tilt_acceleration,    "Tilt Accel", "", 0, 5000, 100, 10, initializeSteppers, enterEvent | exitEvent| updateEvent, wrapStyle)
  ,OP("Save", saveConfig, enterEvent)
  ,OP("Reset", resetConfiguration, enterEvent)
  ,EXIT("<Back")
)

//Panobot Main Menu
MENU(mainMenu,"Main menu",doNothing,noEvent,noStyle
  ,OP("Scan",runScanCallback,enterEvent)
  ,OP("Sphere", runSphereCallback,enterEvent)
  ,OP("Take Picture",doNothing,enterEvent)
  ,SUBMENU(subMenuSetup)
  ,SUBMENU(subMenuHardware)
);

//SmartLCD encoder driver
encoderIn<ENCODER_A_PIN,ENCODER_B_PIN> encoder;
encoderInStream<ENCODER_A_PIN,ENCODER_B_PIN> encStream(encoder,4);
//SmartLCD encoder key and reset button routed to the same "enter" command
keyMap encBtn_map[]={{ENCODER_BTN_PIN,options->getCmdChar(enterCmd)},{DISPLAY_RESET_BTN_PIN,options->getCmdChar(enterCmd)}};//negative pin numbers use internal pull-up, this is on when low
keyIn<2> encButton(encBtn_map);
//combine all streams as input streams
Stream* in[]={&encStream,&encButton,&Serial};
chainStream<3> sencoder(in);

MENU_OUTPUTS(out,MAX_DEPTH
  ,U8G2_OUT(u8g2,colors,fontX,fontY,offsetX,offsetY,{0,0,(128-2*offsetX)/fontX,32/fontY})
  ,SERIAL_OUT(Serial)
);

NAVROOT(nav,mainMenu,MAX_DEPTH,sencoder,out);

config myOptions('*','-',false,false,defaultNavCodes);

//this function writes the Panobot status to the LCD
void drawStatus() {
  enum {BufSize=128/fontX};
  char buf1[BufSize];
  char buf2[BufSize];
  snprintf (buf1, BufSize, "H[%02d/%02d]V[%02d/%02d]",
  g_scanPositionHorizontal+1,
  g_picturesHorizontal,
  g_scanPositionVertical+1,
  g_picturesVertical
  );
  snprintf (buf2, BufSize, "T[%03d/%03d]",
  g_picturesCount,
  g_picturesTotal
  );
  u8g2.drawStr(128 - fontX * strlen(buf1), 8, buf1);
  u8g2.drawStr(128 - fontX * strlen(buf2), 16, buf2);
  g_updateStatus = false;
}

void splashscreen() {
  u8g2.clearBuffer();
  int x;
  int y;
  for (x=0;x<128;x++) {
    for (y=0;y<64;y++) {
      if (pgm_read_byte_near(SPLASHSCREEN + x*64+y) =='1')
        u8g2.drawPixel(x, y);
    }
  }
  u8g2.sendBuffer();
  delay(5000);
}

void setup() {
  loadConfig();
  options = &myOptions;
  //initialize Serial interface
  Serial.begin(115200);
  while(!Serial);
  Serial.println("Panobot");Serial.flush();
  //initialize menu
  u8g2.begin();
  u8g2.setFont(fontName);
  encButton.begin();
  encoder.begin();
  //initialize bot
  setupPanoBot();
  splashscreen();
}

void loop() {
  nav.doInput();
  if (nav.changed(0) || g_updateStatus) {
    u8g2.clearBuffer();
    nav.doOutput();
    //this fixes?? an issue with ArduinoMenu, when the Cursor is over the last entry in a Menu,
    //the color mode/draw is set to XOR?? -> issue bug/question report
    u8g2.setFontMode(1);
    u8g2.setDrawColor(1);
    u8g2.setFont(u8g2_font_ncenB12_tr);
    u8g2.drawStr(0, 32, "PANOBOT");
    u8g2.setFont(fontName);
    drawStatus();
    u8g2.sendBuffer();
  }
  stateMachine();
  panStepper.run();
  tiltStepper.run();
}

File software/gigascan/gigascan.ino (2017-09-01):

#include <LiquidCrystal.h>
#include "MenuLCD.h"
#include "MenuEntry.h"
#include "MenuIntHelper.h"
#include "MenuManager.h"
#include <AccelStepper.h>
#include <math.h>

const int LCDRS = 8;
const int LCDE  = 9;
const int LCDD4 = 4;
const int LCDD5 = 5;
const int LCDD6 = 6;
const int LCDD7 = 7;

const int PAN_STEP_PIN  = 24;
const int PAN_DIR_PIN   = 25;
const int TILT_STEP_PIN = 26;
const int TILT_DIR_PIN = 27;
const int FOCUS_PIN    = 22;
const int SHUTTER_PIN  = 23;

MenuLCD g_menuLCD( LCDRS, LCDE, LCDD4, LCDD5, LCDD6, LCDD7, 16, 2);
MenuManager g_menuManager( &g_menuLCD);

// erstellen einiger Variablen
int Taster = 0;
int Analogwert = 0;
#define Tasterrechts 0
#define Tasteroben 1
#define Tasterunten 2
#define Tasterlinks 3
#define Tasterselect 4
#define KEYPAD_NONE 5
#define KEYPAD_BLOCKED 6

// Ab hier wird ein neuer Programmblock mit dem Namen "Tasterstatus" erstellt. Hier wird ausschließlich ausschließlich geprüft, welcher Taster gedrückt ist.
int Tasterstatus()
{
Analogwert = analogRead(A0); // Auslesen der Taster am Analogen Pin A0.
if (Analogwert > 1000) return KEYPAD_NONE;
if (Analogwert < 50) return Tasterrechts;
if (Analogwert < 195) return Tasteroben;
if (Analogwert < 380) return Tasterunten;
if (Analogwert < 555) return Tasterlinks;
if (Analogwert < 790) return Tasterselect;
 
return KEYPAD_NONE; // Ausgabe wenn kein Taster gedrückt wurde.
}

unsigned long _block_time = 0;
int _last_button;

int blockedButton() {
  // if we are still blocked, return this status
  if (millis() < _block_time)
    return KEYPAD_BLOCKED;

  uint8_t current = Tasterstatus();

  // if some key is pressed, disable presses for block_delay or repeat_delay if button is kept down
  if (current != KEYPAD_NONE)
    _block_time = millis() + (current == _last_button ? 500 : 250);

  _last_button = current;
  return current;  
}


// Menu Structure
// Setup
// |-Max Pan Left
// |-Max Pan Right
// |-Max Tilt Up
// |-Max Tilt Down
// |-Pan Step
// |-Tilt Step
// Run Scan
// Credits

void setMaxPanLeftCallback(char*, void*);
void setMaxPanRightCallback(char*, void*);
void setMaxTiltUpCallback(char*, void*);
void setMaxTiltDownCallback(char*, void*);
void setTakePicturePreDelayCallback(char*, void*);
void setTakePictureDelayCallback(char*, void*);
void setShutterDelayCallback(char*, void*);
void takePictureCallback(char*, void*);
void setFocalLength(char*, void*);
void setHOL(char*, void*);
void setVOL(char*, void*);
void runScanCallback(char*, void*);
int triggerPicture();

void setupMenus()
{
  g_menuLCD.MenuLCDSetup();
  
  MenuEntry * p_menuEntryRoot;
  p_menuEntryRoot = new MenuEntry("Setup", NULL, NULL);
  g_menuManager.addMenuRoot( p_menuEntryRoot );
  g_menuManager.addChild( new MenuEntry("Max Pan Left", NULL, setMaxPanLeftCallback));
  g_menuManager.addChild( new MenuEntry("Max Pan Right", NULL, setMaxPanRightCallback));
  g_menuManager.addChild( new MenuEntry("Max Tilt Up", NULL, setMaxTiltUpCallback));
  g_menuManager.addChild( new MenuEntry("Max Tilt Down", NULL, setMaxTiltDownCallback));
  g_menuManager.addChild( new MenuEntry("Image P-Delay", NULL, setTakePicturePreDelayCallback));
  g_menuManager.addChild( new MenuEntry("Image Delay", NULL, setTakePictureDelayCallback));
  g_menuManager.addChild( new MenuEntry("Shutter Delay", NULL, setShutterDelayCallback));
  g_menuManager.addChild( new MenuEntry("Take Image", NULL, takePictureCallback));
  g_menuManager.addChild( new MenuEntry("Focal Length", NULL, setFocalLength));
  g_menuManager.addChild( new MenuEntry("HOL", NULL, setHOL));
  g_menuManager.addChild( new MenuEntry("VOL", NULL, setVOL));
  
  g_menuManager.addChild( new MenuEntry("Back", (void*) &g_menuManager, MenuEntry_BackCallbackFunc));
  g_menuManager.addSibling( new MenuEntry("Run Scan", NULL, runScanCallback));
  g_menuManager.addSibling( new MenuEntry("Credits", NULL, NULL));
  g_menuManager.DrawMenu();
}

AccelStepper panStepper(AccelStepper::DRIVER, PAN_STEP_PIN, PAN_DIR_PIN);
AccelStepper tiltStepper(AccelStepper::DRIVER, TILT_STEP_PIN, TILT_DIR_PIN);

boolean g_runScan = false;
boolean g_isMaxPanLeftSetup = false;
boolean g_isMaxPanRightSetup = false;
boolean g_isPanStepSetup = false;
boolean g_isMaxTiltUpSetup = false;
boolean g_isMaxTiltDownSetup = false;
boolean g_isTiltStepSetup = false;
boolean g_runScanRight = false;
boolean g_takePicture = false;
boolean g_runTilt = false;
 
int pan_step_per_deg = 7 * 8;
int g_maxPanLeftDeg = -10;
int g_maxPanRightDeg = +10;
double g_panStepDeg = 0;
int tilt_step_per_deg = 35;
int g_maxTiltUpDeg = +10;
int g_maxTiltDownDeg = -10;
double g_tiltStepDeg = 0;
int g_scanPositionHorizontal = 0;
int g_scanPositionVertical = 0;
int g_picturesHorizontal = 0;
int g_picturesVertical = 0;
int g_picturesCount = 0;
int g_picturesTotal = 0;
int g_takePictureDelay = 250;
int g_takePicturePreDelay = 0;
int g_shutterDelay = 500;

double g_crop = 1.6;
double g_sensorFF_horizontal = 36.0;
double g_sensorFF_vertical = 24.0;
int g_focalLength = 300;
int g_hol = 30;
int g_vol = 30;
double g_hfov = 0;
double g_vfov = 0;

void updateScanner() {
  g_hfov = degrees( 2 * atan2(g_sensorFF_horizontal, g_crop * 2 * g_focalLength));
  g_vfov = degrees( 2 * atan2(g_sensorFF_vertical, g_crop * 2 * g_focalLength));
  g_panStepDeg = g_hfov * (100 - g_hol) / 100;
  g_tiltStepDeg = g_vfov * (100 - g_vol) / 100;
  g_picturesHorizontal = ceil((abs(g_maxPanLeftDeg) + abs(g_maxPanRightDeg)) / g_panStepDeg);
  g_picturesVertical = ceil((abs(g_maxTiltUpDeg) + abs(g_maxTiltDownDeg)) / g_tiltStepDeg);
  g_picturesTotal = g_picturesHorizontal * g_picturesVertical;
  Serial.print("HSCAN: "); Serial.println(abs(g_maxPanLeftDeg) + abs(g_maxPanRightDeg), DEC);
  Serial.print("VSCAN: "); Serial.println(abs(g_maxTiltUpDeg) + abs(g_maxTiltDownDeg), DEC);
  Serial.print("g_hfov: "); Serial.println(g_hfov,DEC);
  Serial.print("g_vfov: "); Serial.println(g_vfov,DEC);
  Serial.print("g_panStepDeg: "); Serial.println(g_panStepDeg,DEC);
  Serial.print("g_tiltStepDeg: "); Serial.println(g_tiltStepDeg,DEC);
  Serial.print("g_picturesHorizontal: "); Serial.println(g_picturesHorizontal, DEC);
  Serial.print("g_picturesVertical: "); Serial.println(g_picturesVertical, DEC);
  Serial.print("g_picturesTotal: "); Serial.println(g_picturesTotal, DEC);  
}

void printScannerStats() {
  Serial.print("H["); 
  Serial.print(g_scanPositionHorizontal+1, DEC); 
  Serial.print("/");
  Serial.print(g_picturesHorizontal, DEC);
  Serial.println("]"); 
  Serial.print("V["); 
  Serial.print(g_scanPositionVertical+1, DEC); 
  Serial.print("/");
  Serial.print(g_picturesVertical, DEC);
  Serial.println("]"); 
  Serial.print("T["); 
  Serial.print(g_picturesCount, DEC); 
  Serial.print("/");
  Serial.print(g_picturesTotal, DEC);
  Serial.println("]"); 
}
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

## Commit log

2017-07-06 added gigascan construction files
    [central_gear.stl, central_pan.stl, drivegear.stl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]
2017-07-06 added hardware wiring pictures for stepstick driver and canon remote controller
2017-07-06 added megamount print and initial software
    [megamount.stl]
2017-07-07 added camquickmount
    [camquickmount.stl, gigascan.scad]
2017-07-07 added quickmount clamp for camera quickmount
    [gigascan.scad, quickmountclamp.stl]
2017-07-08 added AccelStepper and Arduino LCD Menu, updated submodule refs
2017-07-08 added Menu and Stepper Library, included Menu & Stepper Testcode into main file
2017-07-08 added/enabled tilt stepper, added tilt step/scan setup
2017-07-15 modified quickcam mount to match mount of andoer professionals mount
    [gigascan.scad]
2017-07-15 added andoer cam quickmount model (stl)
    [camquickmount_andoer.stl]
2017-07-27 refactored for arduino-mk
2017-08-08 Squashed 'software/gigascan/libraries/Arduino_LCD_Menu/' content from commit 5a81bfe
    git-subtree-dir: software/gigascan/libraries/Arduino_LCD_Menu
    git-subtree-split: 5a81bfea3451c79112b9a7ddb2496e45b320413a
2017-08-08 fixed arduino header not found issue
2017-08-09 Squashed 'software/gigascan/libraries/Arduino_Camera_Control/' content from commit 4f5b1bf
    git-subtree-dir: software/gigascan/libraries/Arduino_Camera_Control
    git-subtree-split: 4f5b1bf438d160ee8836b36b7482e28c9e0700b0
2017-08-09 added USB Host Shield & PTP version 1.0, fixed arduino > 1.0 compatibility
2017-08-09 fixed horizontal & vertical overlap error
    [gigascan.ino]
2017-08-10 changed tilt steps per deg to match mechanics, leasons learned - calibrate before :)
2017-08-31 replaced zig-zag scan by line scanning
    [gigascan.ino]
2017-08-31 Squashed 'software/gigascan/libraries/u8g2/' content from commit cf9f713
    git-subtree-dir: software/gigascan/libraries/u8g2
    git-subtree-split: cf9f7134337fa6ad83f3c4143a738a120c9d3775
    [clock.dxf, clock_2.dxf, display.csv]
2017-09-01 added smart lcd case
    [Bottom_Case_FGD-_pockets.stl, Bottom_Case_FGD.stl, Case_Clamp.stl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]
2017-09-01 added wiring diagrams for smart lcd
2017-09-01 controller case, bottom part
    [controller_case_bottom.stl, gigascan.scad]
2017-09-09 arranged parts for printing
    [camquickmount.stl, camquickmount_andoer.stl, central_gear.stl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]
2017-09-12 rerouted smartlcd to use hardware SPI and moved encoder away from SPI pins :/
2017-09-16 updated configuration section, fixed issue with displaying status message, reorganized/commented code
    [config.h, panobot.cpp]
2017-09-18 added simple version of controller box, its not fault free
    [controller_case_cover.stl, gigascan.scad]
2017-10-29 added a schema for the electronic
    [_saved_pcb.sch, pcb.kicad_pcb, pcb.sch]
2017-12-07 updated schema files to match prototype pcb routing
    [pcb.sch]
2017-12-23 updated schematic and added pcb layout
    [_saved_pcb.sch, pcb.kicad_pcb, pcb.sch]
2017-12-23 added spherical scan mode to readme, updated pcb section
2018-01-03 added an improved version of the tilt side, which has larger gears
    [improved_tilt_axis.stl]
2018-01-28 fixed updateScanner printout
2018-02-26 added pcb images for wiki
2018-02-26 added pcb backside picture
